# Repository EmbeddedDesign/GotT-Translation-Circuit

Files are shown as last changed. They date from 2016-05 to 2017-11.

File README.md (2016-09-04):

# GotT Translation Circuit 

GotT is a Bluetooth voice modulator circuit for Daleks



## FAQ

### GotT?

["gift of the Time Lord" or "gift of the TARDIS"](http://tardis.wikia.com/wiki/Translation_circuit) depending upon whether you're a Tom Baker or Christopher Eccleston fan respectively.

### What is a "voice modulator"?

A voice modulator is device for altering (or [modulating](https://en.wikipedia.org/wiki/Modulation)) the sound of one's voice.

In the context of Daleks, this usually refers to [ring modulation](https://en.wikipedia.org/wiki/Ring_modulation), whereby two signals mixed (i.e. - multiplied, or [Heterodyned](https://en.wikipedia.org/wiki/Heterodyne)). The first of these signals is typically a voice and the second is often a [sine wave](https://en.wikipedia.org/wiki/Sine_wave) at a frequency of about 30Hz.

This was originally accomplished through the use of a [Moog Ring Modulator similar to this](http://www.moogmusic.com/products/moogerfoogers/mf-102-ring-modulator).

While purists may argue that nothing sounds quite like a pair of audio transformers connected by a ring of four Germanium diodes (which is where the "ring" in "ring modulator" comes from), like the original Moog, GotT accomplishes this task in software.

GotT is a modern modulator for modern Daleks.

## The Board

### Schematic

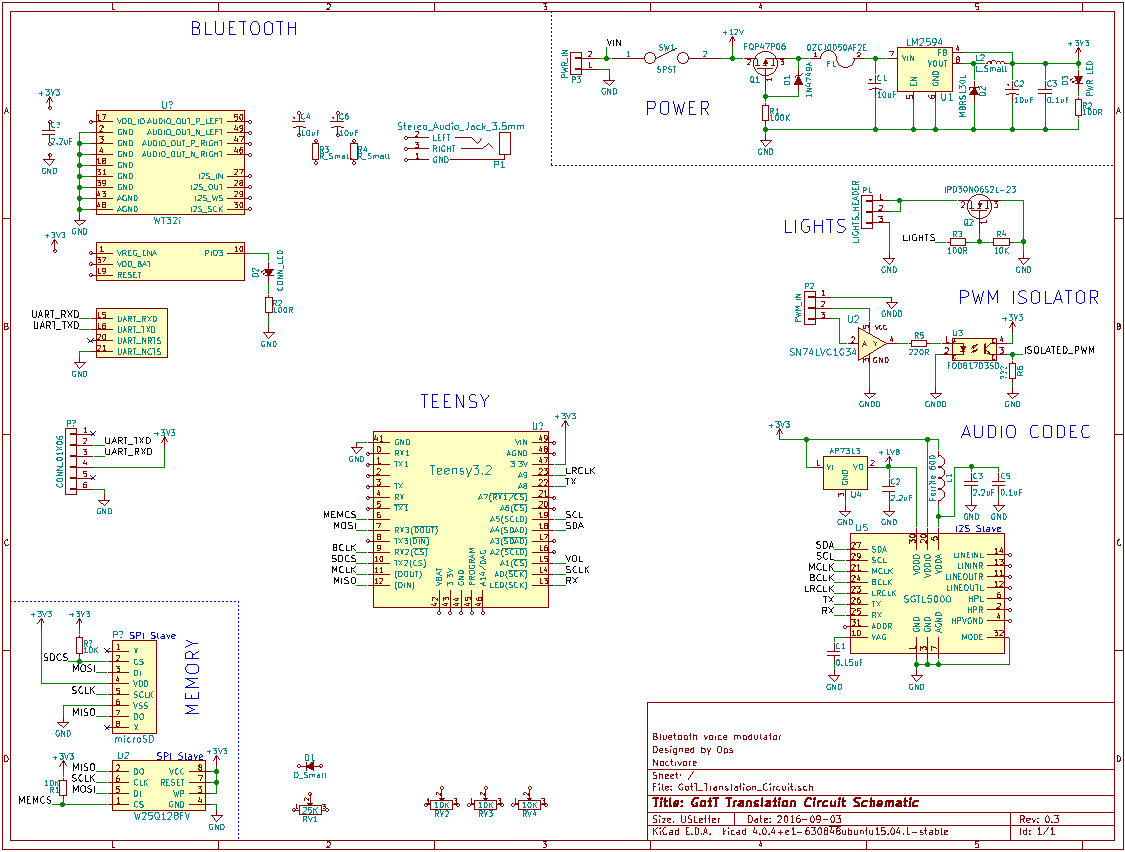
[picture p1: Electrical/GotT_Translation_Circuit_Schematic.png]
GotT Translation Circuit Schematic


All of the design files for the board can be found in the [/Electrical/](https://github.com/EmbeddedDesign/GotT-Translation-Circuit/tree/master/Electrical) subdirectory of this repository.

## Test Boards

Several of the sub-circuits on the GotT including those of the lights, PWM isolator, power, and WT32i were first constructed at test boards to ensure proper concept and functionality prior to integration into the larger design.

A detailed overview of the test boards and deeper descriptions of basic functionality [can be found here](https://noctivore.com/2016/06/12/gott-translation-circuit/).

Images of the schematics and layout along with complete deign files and BOM for each of the test boards can be found in the respective subdirectories of the [/Electrical/Test Boards/](https://github.com/EmbeddedDesign/GotT-Translation-Circuit/tree/master/Electrical/Test%20Boards) section of this repository.

## License

[MIT License](LICENSE) © [Operator](https://github.com/EmbeddedDesign)

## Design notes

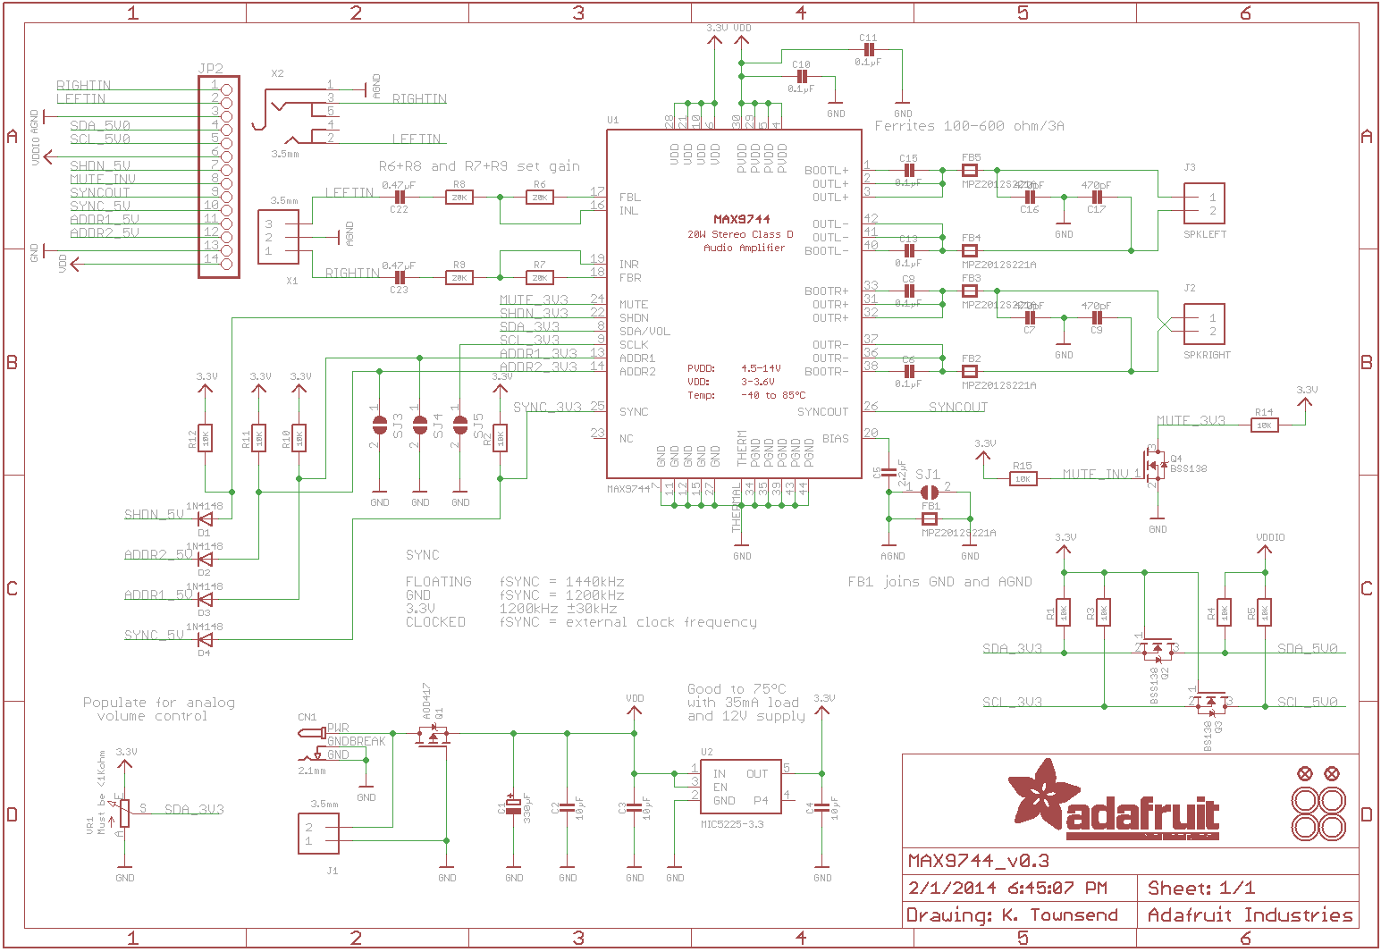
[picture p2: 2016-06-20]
Documentation/Reference Schematics/Adafruit_20W_Stereo_Amp_Schematic.png

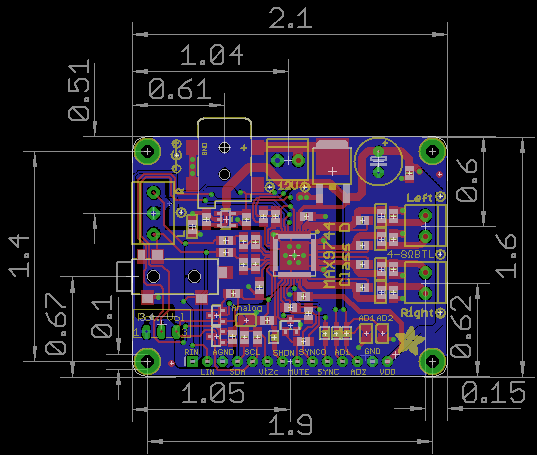
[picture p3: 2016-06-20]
Mechanical/Adafruit_20W_Stereo_Amp_Dimensions_Inch.png

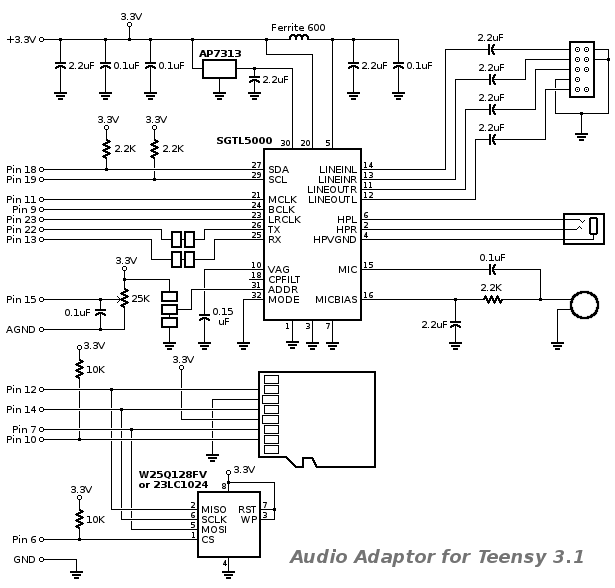
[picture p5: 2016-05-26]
Documentation/Reference Schematics/Teensy3_Audio_Board_Rev2.gif

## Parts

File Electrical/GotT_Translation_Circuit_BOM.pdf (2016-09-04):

GotT Translation Circuit

Page 1

## GotT Translation Circuit BOM

Designator: Quantity: Cost: | Part Number: | Value: | Footprint: | Link: | Alternate Link:
U1 | 1 | $3.28 | LM2594MX-3.3/NOPB | 3.3V, 500mA Switching Regulator
U2 | 1 | $0.36 | SN74LVC1G34DBVR | Buffer, SOT-23-5
U3 | 1 | $0.60 | FOD817D3SD | Optocoupler
U4 | 1 | $0.41 | AP7313-18SAG-7 | 1.8V, 150mA LDO Regulator
U5
U6 | 1 | $1.61 | W25Q128FVSIG | Winbond 128Mb SPI NOR Flash
U7
U8 | 1 | $19.66 WT32i-E-AI6 | WT32i BT Module, U.FL Antenna
Q1 | 1 | $2.25 | FQP47P06 | P-Channel Reverse Protection FET
Q2 | 1 | $0.88 | IPD30N06S2L23ATMA3 | N-Channel MOSFET
D1 | 1 | $0.24 | 1N4749A_T50A | MOSFET Zener Diode
D2 | 1 | $0.44 | 1N5819HW-7-F | Switching Regulator Schottky Diode
D3 | 1 | $0.37 | LG L29K-G2J1-24-Z | PWR LED (Green)
D4 | 1 | $0.35 | LB Q39G-L2OO-35-1 | CONN LED (Blue)
R1 | 1 | $0.10 | CF14JT100K | MOSFET Resistor, 100K Ohm
R2 | 1 | $0.10 | ERJ-3EKF8200V | PWR LED Resistor (820 Ohm), 0603
R3 | 1 | $0.10 | ERJ-3EKF1000V | MOSFET Gate Current Limit Resistor, 1
R4, 7, 8 | 3 | $0.10 | ERJ-3EKF1002V | Pull-up/Pull-down Resistors, 10K Ohm
R5 | 1 | $0.10 | ERJ-3EKF2200V | Input Resistor 220 Ohm, 0603
R6
F1 | 1 | $0.18 | 0ZCJ0050AF2E | PTC Resettable Fuse
C1 | 1 | $0.89 | EEE-FPV680XAP | 68uF Input Bypass Capacitor
C2 | 1 | $1.39 | TPSD107K016R0125 | Output Capacitor, 100uF
C3, 6 | 2 | 0.1uF Filter Capacitors
C4, 5 | 2 | 2.2uF Filter Capacitors
C7 | 1 | 0.15uF Analog Filter Capacitor
L1 | 1 | $3.24 | PE-53820SNL | 115uH Inductor
L2 | 1 | $0.10 | MPZ1608S601ATA00 | Ferrite Bead 600 Ohm at 100MHz
SW1 | 1 | $0.93 | GF-123-0054 | Power Switch
P1
P2 | 1 | $0.53 | 1935174 | Lights Screw Terminal, 01X03
P3 | 1 | $0.27 | 68000-103HLF | 01X03 Male Header
P4
PGT1 | 1 | $4.50 | JF1R6-CR3-4I | U.FL (UMCC) to RP-SMA Female
ANT1 | 1 | $5.00 | 001-0015 | 2.4 GHz u.FL Antenna

Cost/Board:$12.60

http://www.ti.com/lit/ds/symlink/lm2594.pdf https://www.digikey.com/product-detail/en/texas-instruments/LM2594MX-3.3-NOPB/LM2594MX-3.3-NOPBCT-ND/3526877 http://www.mouser.com/ProductDetail/Texas-Instruments/LM2594MX-33-NOPB/?qs=X1J7HmVL2ZEh4uJm8Q5hoQ==
http://www.ti.com/lit/ds/symlink/sn74lvc1g34.pdf https://www.digikey.com/product-detail/en/texas-instruments/SN74LVC1G34DBVR/296-17893-1-ND/738116 http://www.mouser.com/ProductDetail/Texas-Instruments/SN74LVC1G34DBVR/?qs=dT9u2OTAaVXXjYSQb2wcdg==
https://www.fairchildsemi.com/datasheets/FO/FOD817D.pdf https://www.digikey.com/product-detail/en/fairchild-semiconductor/FOD817D3SD/FOD817D3SDCT-ND/3041737 http://www.mouser.com/ProductDetail/Fairchild-Semiconductor/FOD817D3SD/?qs=32VJUWvZ7XaI9Lc6ol43XQ==
http://www.diodes.com/_files/datasheets/AP7313.pdf https://www.digikey.com/product-detail/en/diodes-incorporated/AP7313-18SAG-7/AP7313-18SAG-7DICT-ND/2270838 http://www.mouser.com/ProductDetail/Diodes-Incorporated/AP7313-18SAG-7/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

https://www.winbond.com/resource-files/w25q128fv_revhh1_100913_website1.pdf https://www.digikey.com/product-search/en/integrated-circuits-ics/memory/2556980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

http://www.mouser.com/ds/2/368/Bluegigga%20Technologies_WT32i_Datasheet-558681.pdf https://www.digikey.com/product-detail/en/silicon-labs/WT32I-E-AI6/1446-1037-1-ND/4806564 http://www.mouser.com/ProductDetail/Silicon-Labs-Bluegiga/WT32i-E-AI6/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
https://www.fairchildsemi.com/datasheets/FQ/FQP47P06.pdf https://www.digikey.com/product-detail/en/fairchild-semiconductor/FQP47P06/FQP47P06-ND/1057079 http://www.mouser.com/ProductDetail/Fairchild-Semiconductor/FQP47P06/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
http://www.infineon.com/dgdl/Infineon-IPD30N06S2L_23-DS-v01_00-en.pdf?fileId=db3a304412b407950112b433bafe5d69 https://www.digikey.com/product-detail/en/infineon-technologies/IPD30N06S2L23ATMA3/IPD30N06S2L23ATMA3CT-ND/5440904 http://www.mouser.com/ProductDetail/Infineon-Technologies/IPD30N06S2L23ATMA3/?qs=nKAiUEXvm/A3t2VUC031Ag==
http://www.fairchildsemi.com/datasheets/1N/1N4731A.pdf https://www.digikey.com/product-detail/en/fairchild-semiconductor/1N4749A_T50A/1N4749A_T50AFSCT-ND/3478158 http://www.mouser.com/ProductDetail/Fairchild-Semiconductor/1N4749A_T50A/?qs=9h%2BT/FFCxR/U89fjfSyrjQ==
http://www.diodes.com/_files/datasheets/ds30217.pdf https://www.digikey.com/product-detail/en/diodes-incorporated/1N5819HW-7-F/1N5819HW-FDICT-ND/815283 http://www.mouser.com/ProductDetail/Diodes-Incorporated/1N5819HW-7-F/?qs=NQ47qNm99eDyWTEd07miYA==
http://www.osram-os.com/Graphics/XPic2/00077107_0.pdf https://www.digikey.com/product-detail/en/osram-opto-semiconductors-inc/LG-L29K-G2J1-24-Z/475-2709-1-ND/1938876 http://www.mouser.com/ProductDetail/Osram-Opto-Semiconductor/LG-L29K-G2J1-24-Z/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 (https://media.digikey.com/pdf/Data%20Sheets/Osram%20PDFs/LB_LT%20Q39G.pdf)df/Data Sheets/Osram PDFs/LB_LT Q39G.pdf https://www.digikey.com/product-detail/en/osram-opto-semiconductors-inc/LB-Q39G-L2OO-35-1/475-2816-1-ND/2176355 http://www.mouser.com/ProductDetail/Osram-Opto-Semiconductor/LB-Q39G-L2OO-35-1/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 https://www.digikey.com/product-detail/en/stackpole-electronics-inc/CF14JT100K/CF14JT100KCT-ND/1830399 http://www.mouser.com/ProductDetail/Ohmite/OK1045E-R52/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 https://www.digikey.com/product-detail/en/panasonic-electronic-components/ERJ-3EKF8200V/P820HCT-ND/1746806 http://www.mouser.com/ProductDetail/Panasonic/ERJ-3EKF8200V/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 https://www.digikey.com/product-detail/en/panasonic-electronic-components/ERJ-3EKF1000V/P100HCT-ND/198109 http://www.mouser.com/ProductDetail/Panasonic/ERJ-3EKF1000V/?qs=H7k1u0Mp9JS7i8KGO5m47A==
http://industrial.panasonic.com/www-cgi/jvcr13pz.cgi?E+PZ+3+AOA0002+ERJ3EKF1002V+7+WW https://www.digikey.com/product-detail/en/panasonic-electronic-components/ERJ-3EKF1002V/P10.0KHCT-ND/198102 http://www.mouser.com/ProductDetail/Panasonic/ERJ-3EKF1002V/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 https://www.digikey.com/product-detail/en/panasonic-electronic-components/ERJ-3EKF2200V/P220HCT-ND/1746741 http://www.mouser.com/ProductDetail/Panasonic/ERJ-3EKF2200V/?qs=iBwFsHVUAOcTUCNoJPNpnQ==

http://www.belfuse.com/pdfs/0ZCJ.pdf https://www.digikey.com/product-detail/en/bel-fuse-inc/0ZCJ0050AF2E/507-1803-1-ND/4156312 http://www.mouser.com/ProductDetail/Bel-Fuse/0ZCJ0050AF2E/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 https://www.digikey.com/product-detail/en/panasonic-electronic-components/EEE-FPV680XAP/PCE4553CT-ND/1701052 http://www.mouser.com/ProductDetail/Panasonic/EEE-FPV680XAP/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 https://www.digikey.com/product-detail/en/avx-corporation/TPSD107K016R0125/478-1778-1-ND/564810 http://www.mouser.com/ProductDetail/AVX/TPSD107K016R0125/?qs=Ow%2BOiPmaljGaFh%2BHI/q%2BNg==

http://productfinder.pulseeng.com/products/datasheets/SPM2007_47.pdf https://www.digikey.com/product-detail/en/pulse-electronics-corporation/PE-53820SNL/553-1403-ND/1037014 http://www.mouser.com/ProductDetail/Pulse/PE-53820SNL/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 https://www.digikey.com/product-detail/en/tdk-corporation/MPZ1608S601ATA00/445-2205-1-ND/765103 http://www.mouser.com/ProductDetail/TDK/MPZ1608S601ATA00/?qs=47dIwT2ZIzth0CTKDYh9rw==
https://media.digikey.com/p (https://media.digikey.com/pdf/Data%20Sheets/CW%20Industries%20PDFs/GF-123-0054_Dwg.pdf)df/Data Sheets/CW Industries PDFs/GF-123-0054_Dwg.pdf https://www.digikey.com/product-detail/en/cw-industries/GF-123-0054/CWI333-ND/4089770 http://www.mouser.com/ProductDetail/CW-Industries/GF-123-0054/?qs=n1d6TrdN4SA9FY9ssLiRzw==

https://media.digikey.com/p (https://media.digikey.com/pdf/Data%20Sheets/Phoenix%20Contact%20PDFs/1935174.pdf)df/Data Sheets/Phoenix Contact PDFs/1935174.pdf https://www.digikey.com/product-detail/en/phoenix-contact/1935174/277-1578-ND/568615 http://www.mouser.com/ProductDetail/Phoenix-Contact/1935174/?qs=QWULklcAmSR8B7o4YouITA==
http://portal.fciconnect.com/Comergent//fci/drawing/68000.pdf https://www.digikey.com/product-detail/en/amphenol-fci/68000-103HLF/609-3461-ND/2023309 http://www.mouser.com/ProductDetail/FCI/68000-103HLF/?qs=zh4O8xspOuyqPBhcuxtliw==

http://www.digi.com/products/models/jf1r6-cr3-4i https://www.digikey.com/product-detail/en/digi-international/JF1R6-CR3-4I/JF1R6-CR3-4I-ND/1090366 http://www.mouser.com/ProductDetail/Digi-International/JF1R6-CR3-4I/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 https://www.digikey.com/product-detail/en/lsr/001-0015/001-0015-ND/4732759 http://www.mouser.com/ProductDetail/LS-Research/001-0015/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 DRAFT

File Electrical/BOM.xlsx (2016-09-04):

GotT Translation Circuit BOM
Designator: | Quantity: | Cost: | Part Number: | Value: | Footprint: | Link: | Alternate Link:
U1 | 1 | $3.28 | LM2594MX-3.3/NOPB | 3.3V, 500mA Switching Regulator | http://www.ti.com/lit/ds/symlink/lm2594.pdf | https://www.digikey.com/product-detail/en/texas-instruments/LM2594MX-3.3-NOPB/LM2594MX-3.3-NOPBCT-ND/3526877 | http://www.mouser.com/ProductDetail/Texas-Instruments/LM2594MX-33-NOPB/?qs=X1J7HmVL2ZEh4uJm8Q5hoQ==
U2 | 1 | $0.36 | SN74LVC1G34DBVR | Buffer, SOT-23-5 | http://www.ti.com/lit/ds/symlink/sn74lvc1g34.pdf | https://www.digikey.com/product-detail/en/texas-instruments/SN74LVC1G34DBVR/296-17893-1-ND/738116 | http://www.mouser.com/ProductDetail/Texas-Instruments/SN74LVC1G34DBVR/?qs=dT9u2OTAaVXXjYSQb2wcdg==
U3 | 1 | $0.60 | FOD817D3SD | Optocoupler | https://www.fairchildsemi.com/datasheets/FO/FOD817D.pdf | https://www.digikey.com/product-detail/en/fairchild-semiconductor/FOD817D3SD/FOD817D3SDCT-ND/3041737 | http://www.mouser.com/ProductDetail/Fairchild-Semiconductor/FOD817D3SD/?qs=32VJUWvZ7XaI9Lc6ol43XQ==
U4 | 1 | $0.41 | AP7313-18SAG-7 | 1.8V, 150mA LDO Regulator | http://www.diodes.com/_files/datasheets/AP7313.pdf | https://www.digikey.com/product-detail/en/diodes-incorporated/AP7313-18SAG-7/AP7313-18SAG-7DICT-ND/2270838 | http://www.mouser.com/ProductDetail/Diodes-Incorporated/AP7313-18SAG-7/
U5
U6 | 1 | $1.61 | W25Q128FVSIG | Winbond 128Mb SPI NOR Flash | https://www.winbond.com/resource-files/w25q128fv_revhh1_100913_website1.pdf | https://www.digikey.com/product-search/en/integrated-circuits-ics/memory/2556980?k=w25q128fv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
U7
U8 | 1 | $19.66 | WT32i-E-AI6 | WT32i BT Module, U.FL Antenna | http://www.mouser.com/ds/2/368/Bluegigga%20Technologies_WT32i_Datasheet-558681.pdf | https://www.digikey.com/product-detail/en/silicon-labs/WT32I-E-AI6/1446-1037-1-ND/4806564 | http://www.mouser.com/ProductDetail/Silicon-Labs-Bluegiga/WT32i-E-AI6/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
Q1 | 1 | $2.25 | FQP47P06 | P-Channel Reverse Protection FET | https://www.fairchildsemi.com/datasheets/FQ/FQP47P06.pdf | https://www.digikey.com/product-detail/en/fairchild-semiconductor/FQP47P06/FQP47P06-ND/1057079 | http://www.mouser.com/ProductDetail/Fairchild-Semiconductor/FQP47P06/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
Q2 | 1 | $0.88 | IPD30N06S2L23ATMA3 | N-Channel MOSFET | http://www.infineon.com/dgdl/Infineon-IPD30N06S2L_23-DS-v01_00-en.pdf?fileId=db3a304412b407950112b433bafe5d69 | https://www.digikey.com/product-detail/en/infineon-technologies/IPD30N06S2L23ATMA3/IPD30N06S2L23ATMA3CT-ND/5440904 | http://www.mouser.com/ProductDetail/Infineon-Technologies/IPD30N06S2L23ATMA3/?qs=nKAiUEXvm/A3t2VUC031Ag==
D1 | 1 | $0.24 | 1N4749A_T50A | MOSFET Zener Diode | http://www.fairchildsemi.com/datasheets/1N/1N4731A.pdf | https://www.digikey.com/product-detail/en/fairchild-semiconductor/1N4749A_T50A/1N4749A_T50AFSCT-ND/3478158 | http://www.mouser.com/ProductDetail/Fairchild-Semiconductor/1N4749A_T50A/?qs=9h%2BT/FFCxR/U89fjfSyrjQ==
D2 | 1 | $0.44 | 1N5819HW-7-F | Switching Regulator Schottky Diode | http://www.diodes.com/_files/datasheets/ds30217.pdf | https://www.digikey.com/product-detail/en/diodes-incorporated/1N5819HW-7-F/1N5819HW-FDICT-ND/815283 | http://www.mouser.com/ProductDetail/Diodes-Incorporated/1N5819HW-7-F/?qs=NQ47qNm99eDyWTEd07miYA==
D3 | 1 | $0.37 | LG L29K-G2J1-24-Z | PWR LED (Green) | http://www.osram-os.com/Graphics/XPic2/00077107_0.pdf | https://www.digikey.com/product-detail/en/osram-opto-semiconductors-inc/LG-L29K-G2J1-24-Z/475-2709-1-ND/1938876 | http://www.mouser.com/ProductDetail/Osram-Opto-Semiconductor/LG-L29K-G2J1-24-Z/
D4 | 1 | $0.35 | LB Q39G-L2OO-35-1 | CONN LED (Blue) | https://media.digikey.com/pdf/Data Sheets/Osram PDFs/LB_LT Q39G.pdf (https://media.digikey.com/pdf/Data%20Sheets/Osram%20PDFs/LB_LT%20Q39G.pdf) | https://www.digikey.com/product-detail/en/osram-opto-semiconductors-inc/LB-Q39G-L2OO-35-1/475-2816-1-ND/2176355 | http://www.mouser.com/ProductDetail/Osram-Opto-Semiconductor/LB-Q39G-L2OO-35-1/
R1 | 1 | $0.10 | CF14JT100K | MOSFET Resistor, 100K Ohm | http://www.seielect.com/catalog/SEI-CF_CFM.pdf | https://www.digikey.com/product-detail/en/stackpole-electronics-inc/CF14JT100K/CF14JT100KCT-ND/1830399 | http://www.mouser.com/ProductDetail/Ohmite/OK1045E-R52/?qs=sGAEpiMZZMsPqMdJzcrNwhqiT%2B35FJji0CucJiszflQ=
R2 | 1 | $0.10 | ERJ-3EKF8200V | PWR LED Resistor (820 Ohm), 0603 | http://industrial.panasonic.com/www-cgi/jvcr13pz.cgi?E+PZ+3+AOA0002+ERJ3EKF8200V+7+WW | https://www.digikey.com/product-detail/en/panasonic-electronic-components/ERJ-3EKF8200V/P820HCT-ND/1746806 | http://www.mouser.com/ProductDetail/Panasonic/ERJ-3EKF8200V/
R3 | 1 | $0.10 | ERJ-3EKF1000V | MOSFET Gate Current Limit Resistor, 100 Ohm | http://industrial.panasonic.com/www-cgi/jvcr13pz.cgi?E+PZ+3+AOA0002+ERJ3EKF1000V+7+WW | https://www.digikey.com/product-detail/en/panasonic-electronic-components/ERJ-3EKF1000V/P100HCT-ND/198109 | http://www.mouser.com/ProductDetail/Panasonic/ERJ-3EKF1000V/?qs=H7k1u0Mp9JS7i8KGO5m47A==
R4, 7, 8 | 3 | $0.10 | ERJ-3EKF1002V | Pull-up/Pull-down Resistors, 10K Ohm | http://industrial.panasonic.com/www-cgi/jvcr13pz.cgi?E+PZ+3+AOA0002+ERJ3EKF1002V+7+WW | https://www.digikey.com/product-detail/en/panasonic-electronic-components/ERJ-3EKF1002V/P10.0KHCT-ND/198102 | http://www.mouser.com/ProductDetail/Panasonic/ERJ-3EKF1002V/?qs=H7k1u0Mp9JSrGPQ5/5COuw==
R5 | 1 | $0.10 | ERJ-3EKF2200V | Input Resistor 220 Ohm, 0603 | http://industrial.panasonic.com/www-cgi/jvcr13pz.cgi?E+PZ+3+AOA0002+ERJ3EKF2200V+7+WW | https://www.digikey.com/product-detail/en/panasonic-electronic-components/ERJ-3EKF2200V/P220HCT-ND/1746741 | http://www.mouser.com/ProductDetail/Panasonic/ERJ-3EKF2200V/?qs=iBwFsHVUAOcTUCNoJPNpnQ==
R6
F1 | 1 | $0.18 | 0ZCJ0050AF2E | PTC Resettable Fuse | http://www.belfuse.com/pdfs/0ZCJ.pdf | https://www.digikey.com/product-detail/en/bel-fuse-inc/0ZCJ0050AF2E/507-1803-1-ND/4156312 | http://www.mouser.com/ProductDetail/Bel-Fuse/0ZCJ0050AF2E/?qs=SRYZG9HaIQ3Oqm1PQp276Q==
C1 | 1 | $0.89 | EEE-FPV680XAP | 68uF Input Bypass Capacitor | http://industrial.panasonic.com/cdbs/www-data/pdf/RDE0000/ABA0000C1184.pdf | https://www.digikey.com/product-detail/en/panasonic-electronic-components/EEE-FPV680XAP/PCE4553CT-ND/1701052 | http://www.mouser.com/ProductDetail/Panasonic/EEE-FPV680XAP/?qs=d1CqaRUMZD%2BB3QneHdz%2BNA==
C2 | 1 | $1.39 | TPSD107K016R0125 | Output Capacitor, 100uF | http://datasheets.avx.com/tps.pdf | https://www.digikey.com/product-detail/en/avx-corporation/TPSD107K016R0125/478-1778-1-ND/564810 | http://www.mouser.com/ProductDetail/AVX/TPSD107K016R0125/?qs=Ow%2BOiPmaljGaFh%2BHI/q%2BNg==
C3, 6 | 2 |  |  | 0.1uF Filter Capacitors
C4, 5 | 2 |  |  | 2.2uF Filter Capacitors
C7 | 1 |  |  | 0.15uF Analog Filter Capacitor
L1 | 1 | $3.24 | PE-53820SNL | 115uH Inductor | http://productfinder.pulseeng.com/products/datasheets/SPM2007_47.pdf | https://www.digikey.com/product-detail/en/pulse-electronics-corporation/PE-53820SNL/553-1403-ND/1037014 | http://www.mouser.com/ProductDetail/Pulse/PE-53820SNL/?qs=sGAEpiMZZMsg%2By3WlYCkU6/kcGZFUWykAerZ435ceU4=
L2 | 1 | $0.10 | MPZ1608S601ATA00 | Ferrite Bead 600 Ohm at 100MHz | https://product.tdk.com/info/en/catalog/datasheets/beads_commercial_power_mpz1608_en.pdf | https://www.digikey.com/product-detail/en/tdk-corporation/MPZ1608S601ATA00/445-2205-1-ND/765103 | http://www.mouser.com/ProductDetail/TDK/MPZ1608S601ATA00/?qs=47dIwT2ZIzth0CTKDYh9rw==
SW1 | 1 | $0.93 | GF-123-0054 | Power Switch | https://media.digikey.com/pdf/Data Sheets/CW Industries PDFs/GF-123-0054_Dwg.pdf (https://media.digikey.com/pdf/Data%20Sheets/CW%20Industries%20PDFs/GF-123-0054_Dwg.pdf) | https://www.digikey.com/product-detail/en/cw-industries/GF-123-0054/CWI333-ND/4089770 | http://www.mouser.com/ProductDetail/CW-Industries/GF-123-0054/?qs=n1d6TrdN4SA9FY9ssLiRzw==
P1
P2 | 1 | $0.53 | 1935174 | Lights Screw Terminal, 01X03 | https://media.digikey.com/pdf/Data Sheets/Phoenix Contact PDFs/1935174.pdf (https://media.digikey.com/pdf/Data%20Sheets/Phoenix%20Contact%20PDFs/1935174.pdf) | https://www.digikey.com/product-detail/en/phoenix-contact/1935174/277-1578-ND/568615 | http://www.mouser.com/ProductDetail/Phoenix-Contact/1935174/?qs=QWULklcAmSR8B7o4YouITA==
P3 | 1 | $0.27 | 68000-103HLF | 01X03 Male Header | http://portal.fciconnect.com/Comergent//fci/drawing/68000.pdf | https://www.digikey.com/product-detail/en/amphenol-fci/68000-103HLF/609-3461-ND/2023309 | http://www.mouser.com/ProductDetail/FCI/68000-103HLF/?qs=zh4O8xspOuyqPBhcuxtliw==
P4
PGT1 | 1 | $4.50 | JF1R6-CR3-4I | U.FL (UMCC) to RP-SMA Female | http://www.digi.com/products/models/jf1r6-cr3-4i | https://www.digikey.com/product-detail/en/digi-international/JF1R6-CR3-4I/JF1R6-CR3-4I-ND/1090366 | http://www.mouser.com/ProductDetail/Digi-International/JF1R6-CR3-4I/
ANT1 | 1 | $5.00 | 001-0015 | 2.4 GHz u.FL Antenna | http://www.lsr.com/downloads/products/330-0150.pdf | https://www.digikey.com/product-detail/en/lsr/001-0015/001-0015-ND/4732759 | http://www.mouser.com/ProductDetail/LS-Research/001-0015/
 | Cost/Board: | $12.60

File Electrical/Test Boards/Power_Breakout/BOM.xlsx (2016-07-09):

Designator: | Quantity: | Cost: | Part Number: | Value: | Footprint: | Link: | Link (Alternate):
U1 | 1 | $3.28 | LM2594MX-3.3/NOPB | 3.3V, 500mA Switching Regulator | http://www.ti.com/lit/ds/symlink/lm2594.pdf | https://www.digikey.com/product-detail/en/texas-instruments/LM2594MX-3.3-NOPB/LM2594MX-3.3-NOPBCT-ND/3526877 | http://www.mouser.com/ProductDetail/Texas-Instruments/LM2594MX-33-NOPB/?qs=X1J7HmVL2ZEh4uJm8Q5hoQ==
Q1 | 1 | $2.25 | FQP47P06 | P-Channel Reverse Protection FET | https://www.fairchildsemi.com/datasheets/FQ/FQP47P06.pdf | https://www.digikey.com/product-detail/en/fairchild-semiconductor/FQP47P06/FQP47P06-ND/1057079 | http://www.mouser.com/ProductDetail/Fairchild-Semiconductor/FQP47P06/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
D1 | 1 | $0.24 | 1N4749A_T50A | MOSFET Zener Diode | http://www.fairchildsemi.com/datasheets/1N/1N4731A.pdf | https://www.digikey.com/product-detail/en/fairchild-semiconductor/1N4749A_T50A/1N4749A_T50AFSCT-ND/3478158 | http://www.mouser.com/ProductDetail/Fairchild-Semiconductor/1N4749A_T50A/?qs=9h%2BT/FFCxR/U89fjfSyrjQ==
D2 | 1 | $0.44 | 1N5819HW-7-F | Switching Regulator Schottky Diode | http://www.diodes.com/_files/datasheets/ds30217.pdf | https://www.digikey.com/product-detail/en/diodes-incorporated/1N5819HW-7-F/1N5819HW-FDICT-ND/815283 | http://www.mouser.com/ProductDetail/Diodes-Incorporated/1N5819HW-7-F/?qs=NQ47qNm99eDyWTEd07miYA==
D3 | 1 | $0.35 | LB Q39G-L2OO-35-1 | PWR LED (Blue) | https://media.digikey.com/pdf/Data Sheets/Osram PDFs/LB_LT Q39G.pdf (https://media.digikey.com/pdf/Data%20Sheets/Osram%20PDFs/LB_LT%20Q39G.pdf) | https://www.digikey.com/product-detail/en/osram-opto-semiconductors-inc/LB-Q39G-L2OO-35-1/475-2816-1-ND/2176355 | http://www.mouser.com/ProductDetail/Osram-Opto-Semiconductor/LB-Q39G-L2OO-35-1/
R1 | 1 | $0.10 | CF14JT100K | MOSFET Resistor, 100K Ohm | http://www.seielect.com/catalog/SEI-CF_CFM.pdf | https://www.digikey.com/product-detail/en/stackpole-electronics-inc/CF14JT100K/CF14JT100KCT-ND/1830399 | http://www.mouser.com/ProductDetail/Ohmite/OK1045E-R52/?qs=sGAEpiMZZMsPqMdJzcrNwhqiT%2B35FJji0CucJiszflQ=
R2 | 1 | $0.10 | ERJ-3EKF1000V | PWR LED Resistor, 100 Ohm, 0603 | http://industrial.panasonic.com/www-cgi/jvcr13pz.cgi?E+PZ+3+AOA0002+ERJ3EKF1000V+7+WW | https://www.digikey.com/product-detail/en/panasonic-electronic-components/ERJ-3EKF1000V/P100HCT-ND/198109 | http://www.mouser.com/ProductDetail/Panasonic/ERJ-3EKF1000V/
F1 | 1 | $0.18 | 0ZCJ0050AF2E | PTC Resettable Fuse | http://www.belfuse.com/pdfs/0ZCJ.pdf | https://www.digikey.com/product-detail/en/bel-fuse-inc/0ZCJ0050AF2E/507-1803-1-ND/4156312 | http://www.mouser.com/ProductDetail/Bel-Fuse/0ZCJ0050AF2E/?qs=SRYZG9HaIQ3Oqm1PQp276Q==
C1 | 1 | $0.89 | EEE-FPV680XAP | 68uF Input Bypass Capacitor | http://industrial.panasonic.com/cdbs/www-data/pdf/RDE0000/ABA0000C1184.pdf | https://www.digikey.com/product-detail/en/panasonic-electronic-components/EEE-FPV680XAP/PCE4553CT-ND/1701052 | http://www.mouser.com/ProductDetail/Panasonic/EEE-FPV680XAP/?qs=d1CqaRUMZD%2BB3QneHdz%2BNA==
C2 | 1 | $1.39 | TPSD107K016R0125 | Output Capacitor, 100uF | http://datasheets.avx.com/tps.pdf | https://www.digikey.com/product-detail/en/avx-corporation/TPSD107K016R0125/478-1778-1-ND/564810 | http://www.mouser.com/ProductDetail/AVX/TPSD107K016R0125/?qs=Ow%2BOiPmaljGaFh%2BHI/q%2BNg==
L1 | 1 | $3.24 | PE-53820SNL | 115uH Inductor | http://productfinder.pulseeng.com/products/datasheets/SPM2007_47.pdf | https://www.digikey.com/product-detail/en/pulse-electronics-corporation/PE-53820SNL/553-1403-ND/1037014 | http://www.mouser.com/ProductDetail/Pulse/PE-53820SNL/?qs=sGAEpiMZZMsg%2By3WlYCkU6/kcGZFUWykAerZ435ceU4=
S1 | 1 | $0.93 | GF-123-0054 | Power Switch | https://media.digikey.com/pdf/Data Sheets/CW Industries PDFs/GF-123-0054_Dwg.pdf (https://media.digikey.com/pdf/Data%20Sheets/CW%20Industries%20PDFs/GF-123-0054_Dwg.pdf) | https://www.digikey.com/product-detail/en/cw-industries/GF-123-0054/CWI333-ND/4089770 | http://www.mouser.com/ProductDetail/CW-Industries/GF-123-0054/?qs=n1d6TrdN4SA9FY9ssLiRzw==
CON1 | 1 | $1.96 | PJ-036AH-SMT-TR | DC Barrel Jack | http://www.cui.com/product/resource/digikeypdf/pj-036ah-smt.pdf | https://www.digikey.com/product-detail/en/cui-inc/PJ-036AH-SMT-TR/CP-036AHPJCT-ND/1530994 | http://www.mouser.com/ProductDetail/CUI/PJ-036AH-SMT-TR/?qs=WyjlAZoYn52SyDl2EH3QRQ==
TP1,2,3,4 | 4 | $0.16 | RCS-0C | Test Point | http://www.te.com/commerce/DocumentDelivery/DDEController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 | https://www.digikey.com/product-detail/en/te-connectivity-amp-connectors/RCS-0C/A106143CT-ND/3477800 | http://www.mouser.com/ProductDetail/TE-Connectivity-Holsworthy/RCS-0C/?qs=ip69W3eHERVjlVbETUUe0w==
 | 1 | $0.56 | SQP500JB-6R8 | 485mA Dummy Load, 5W | http://www.yageo.com/documents/recent/Yageo LR_SQP NSP_2013.pdf | https://www.digikey.com/product-detail/en/yageo/SQP500JB-6R8/6.8W-5-ND/18651 | http://www.mouser.com/ProductDetail/ARCOL-Ohmite/ACS-5s-6R8-J-TR/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
 | Cost/Board: | $16.55

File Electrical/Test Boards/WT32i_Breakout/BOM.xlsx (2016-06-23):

Designator: | Quantity: | Cost: | Part Number: | Value: | Footprint: | Link: | Link (Alternate): | Alternate Part: | Link: | Link (Alternate):
U1 | 1 | $19.66 | WT32i-E-AI6 | WT32i u.FL Antenna | https://media.digikey.com/pdf/Data Sheets/BlueGiga PDFs/WT32i_DS_V1.21.pdf (https://media.digikey.com/pdf/Data%20Sheets/BlueGiga%20PDFs/WT32i_DS_V1.21.pdf) | https://www.digikey.com/product-detail/en/silicon-labs/WT32I-E-AI6/1446-1037-1-ND/4806564 | http://www.mouser.com/ProductDetail/Bluegiga-Technologies/WT32i-E-AI6/
U2 | 1 | $0.92 | TPS79933DDCR | 3.3V LDO Regulator | http://www.ti.com/lit/ds/symlink/tps799.pdf | https://www.digikey.com/product-search/en/integrated-circuits-ics/pmic-voltage-regulators-linear/2556290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 | http://www.mouser.com/ProductDetail/Texas-Instruments/TPS79933DDCR/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
P4 | 1 | $1.34 | SJ-3523-SMT-TR | 3.5mm Stereo Jack | http://www.cui.com/product/resource/digikeypdf/sj-352x-smt_series.pdf | https://www.digikey.com/product-search/en/connectors-interconnects/barrel-audio-connectors/1443095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 | http://www.mouser.com/ProductDetail/CUI-Inc/SJ-3523-SMT-TR/
D2 | 1 | $0.35 | LB Q39G-L2OO-35-1 | CONN LED (Blue) | https://media.digikey.com/pdf/Data Sheets/Osram PDFs/LB_LT Q39G.pdf (https://media.digikey.com/pdf/Data%20Sheets/Osram%20PDFs/LB_LT%20Q39G.pdf) | https://www.digikey.com/product-detail/en/osram-opto-semiconductors-inc/LB-Q39G-L2OO-35-1/475-2816-1-ND/2176355 | http://www.mouser.com/ProductDetail/Osram-Opto-Semiconductor/LB-Q39G-L2OO-35-1/
D3 | 1 | $0.37 | LG L29K-G2J1-24-Z | PWR LED (Green) | http://www.osram-os.com/Graphics/XPic2/00077107_0.pdf | https://www.digikey.com/product-detail/en/osram-opto-semiconductors-inc/LG-L29K-G2J1-24-Z/475-2709-1-ND/1938876 | http://www.mouser.com/ProductDetail/Osram-Opto-Semiconductor/LG-L29K-G2J1-24-Z/
C1,2 | 2 | $0.12 | GRM188R61C225KE15D | 2.2uF Ceramic Cpacitor, 0603 | http://search.murata.co.jp/Ceramy/image/img/A01X/G101/ENG/GRM188R61C225KE15-01.pdf | https://www.digikey.com/product-detail/en/murata-electronics-north-america/GRM188R61C225KE15D/490-3296-1-ND/702837 | http://www.mouser.com/ProductDetail/Murata-Electronics/GRM188R61C225KE15D/?qs=hib6TRO3foO3n4uH6cyJAg==
C3,4 | 2 | $2.17 | 6TPF330M9L | 330uF/6.3V/20%/TAN/ESR<10mOhm | http://www.kemet.com/docfinder?Partnumber=T520 | https://www.digikey.com/product-detail/en/kemet/T520D337M006ATE009/399-10418-1-ND/3880189 | http://www.mouser.com/ProductDetail/Kemet/T520D337M006ATE009/?qs=F4vAmCFCeavzfa2EBT2i1w== | 6TPF330M9L | https://www.digikey.com/product-detail/en/panasonic-electronic-components/6TPF330M9L/P16258CT-ND/4146701 | http://www.mouser.com/ProductDetail/Panasonic/6TPF330M9L/
C5,6 | 2 | $0.16 | GRM1885C1H330FA01D | 33pF/50V/C0G/+/-0.5pF, 0603 | http://www.murata.com/~/media/webrenewal/support/library/catalog/products/capacitor/mlcc/c02e.pdf | https://www.digikey.com/product-detail/en/murata-electronics-north-america/GRM1885C1H330FA01D/490-9720-1-ND/4934879 | http://www.mouser.com/ProductDetail/Murata-Electronics/GRM1885C1H330FA01D/?qs=ECEo0ueu72kvzV2E3JDz6g==
L1,2 | 2 | $0.10 | MLK1005S33NJT000 | 33nH+/-5%, 200mA, 0.9ohm, 0402 | https://product.tdk.com/info/en/catalog/datasheets/inductor_commercial_high-frequency_mlk1005_en.pdf | https://www.digikey.com/product-detail/en/tdk-corporation/MLK1005S33NJT000/445-1473-1-ND/571781 | http://www.mouser.com/ProductDetail/TDK/MLK1005S33NJT000/?qs=/PzWLGNeQ%2Bg00frD1iDUEg==
R1 | 1 | $0.10 | ERJ-3EKF1000V | CONN LED Resistor (100 Ohm), 0603 | http://industrial.panasonic.com/www-cgi/jvcr13pz.cgi?E+PZ+3+AOA0002+ERJ3EKF1000V+7+WW | https://www.digikey.com/product-detail/en/panasonic-electronic-components/ERJ-3EKF1000V/P100HCT-ND/198109 | http://www.mouser.com/ProductDetail/Panasonic/ERJ-3EKF1000V/
R2 | 1 | $0.10 | ERJ-3EKF8200V | PWR LED Resistor (820 Ohm), 0603 | http://industrial.panasonic.com/www-cgi/jvcr13pz.cgi?E+PZ+3+AOA0002+ERJ3EKF8200V+7+WW | https://www.digikey.com/product-detail/en/panasonic-electronic-components/ERJ-3EKF8200V/P820HCT-ND/1746806 | http://www.mouser.com/ProductDetail/Panasonic/ERJ-3EKF8200V/
R3,4 | 2 | $0.10 | ERJ-3GEYJ105V | 1M/50V/0.1W/5%, 0603 | http://industrial.panasonic.com/www-cgi/jvcr13pz.cgi?E+PZ+3+AOA0001+ERJ3GEYJ105V+7+WW | https://www.digikey.com/product-search/en/resistors/chip-resistor-surface-mount/65769?k=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 | http://www.mouser.com/ProductDetail/Panasonic/ERJ-3GEYJ105V/?qs=66DK8nO8gJAFuT6JGu2rQw==
P1 | 1 | $0.32 | 68000-206HLF | 01X06 Male Through Hole Header | http://portal.fciconnect.com/Comergent//fci/drawing/68000.pdf | https://www.digikey.com/product-detail/en/amphenol-fci/68000-206HLF/609-3256-ND/1878496 | http://www.mouser.com/ProductDetail/FCI-Amphenol/68000-206HLF/
P2 | 1 | $0.32 | 68000-104HLF | 01X04 Male Through Hole Header | http://portal.fciconnect.com/Comergent//fci/drawing/68000.pdf | https://www.digikey.com/product-detail/en/amphenol-fci/68000-104HLF/609-3248-ND/1878462 | http://www.mouser.com/ProductDetail/Amphenol-FCI/68000-104HLF/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
P3 | 1 | $0.27 | 68000-103HLF | 01X03 Male Through Hole Header | http://portal.fciconnect.com/Comergent//fci/drawing/68000.pdf | https://www.digikey.com/product-detail/en/amphenol-fci/68000-103HLF/609-3461-ND/2023309 | http://www.mouser.com/ProductDetail/Amphenol-FCI/68000-103HLF/?qs=zh4O8xspOuyqPBhcuxtliw==
ANT1 | 1 | $5.00 | 001-0015 | 2.4 GHz u.FL Antenna | http://www.lsr.com/downloads/products/330-0150.pdf | https://www.digikey.com/product-detail/en/lsr/001-0015/001-0015-ND/4732759 | http://www.mouser.com/ProductDetail/LS-Research/001-0015/
 | Cost/Board: | #VALUE!

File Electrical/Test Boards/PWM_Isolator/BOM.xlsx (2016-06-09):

Designator: | Quantity: | Cost: | Part Number: | Value: | Footprint: | Link: | Link (Alternate):
U1 | 1 | $0.36 | SN74LVC1G34DBVR | Buffer, SOT-23-5 | http://www.ti.com/lit/ds/symlink/sn74lvc1g34.pdf | https://www.digikey.com/product-detail/en/texas-instruments/SN74LVC1G34DBVR/296-17893-1-ND/738116 | http://www.mouser.com/ProductDetail/Texas-Instruments/SN74LVC1G34DBVR/?qs=dT9u2OTAaVXXjYSQb2wcdg==
U2 | 1 | $0.60 | FOD817D3SD | Optocoupler | https://www.fairchildsemi.com/datasheets/FO/FOD817D.pdf | https://www.digikey.com/product-detail/en/fairchild-semiconductor/FOD817D3SD/FOD817D3SDCT-ND/3041737 | http://www.mouser.com/ProductDetail/Fairchild-Semiconductor/FOD817D3SD/?qs=32VJUWvZ7XaI9Lc6ol43XQ==
R1 | 1 | $0.10 | ERJ-3EKF2200V | Input Resistor 220 Ohm, 0603 | http://industrial.panasonic.com/www-cgi/jvcr13pz.cgi?E+PZ+3+AOA0002+ERJ3EKF2200V+7+WW | https://www.digikey.com/product-detail/en/panasonic-electronic-components/ERJ-3EKF2200V/P220HCT-ND/1746741 | http://www.mouser.com/ProductDetail/Panasonic/ERJ-3EKF2200V/?qs=iBwFsHVUAOcTUCNoJPNpnQ==
RV1 | 1 | $0.43 | 3306F-1-103 | Output Trimmer Potentiometer | http://www.bourns.com/docs/Product-Datasheets/3306.pdf | https://www.digikey.com/product-detail/en/bourns-inc/3306F-1-103/3306F-103-ND/84666 | http://www.mouser.com/ProductDetail/Bourns/3306F-1-103/?qs=lKPmECyLdCwn927ZmtxV0Q==
P1 | 1 | $0.27 | 68000-103HLF | 01X03 Male Header | http://portal.fciconnect.com/Comergent//fci/drawing/68000.pdf | https://www.digikey.com/product-detail/en/amphenol-fci/68000-103HLF/609-3461-ND/2023309 | http://www.mouser.com/ProductDetail/FCI/68000-103HLF/?qs=zh4O8xspOuyqPBhcuxtliw==
 | Cost/Board: | $1.76

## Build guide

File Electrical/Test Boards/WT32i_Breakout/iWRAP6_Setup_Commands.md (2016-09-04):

    +-----------------------------------------------------------------------+
    | A -    Serial Device      : /dev/ttyUSB0                              |
    | B - Lockfile Location     : /var/lock                                 |
    | C -   Callin Program      :                                           |
    | D -  Callout Program      :                                           |
    | E -    Bps/Par/Bits       : 115200 8N1                                |
    | F - Hardware Flow Control : No                                        |
    | G - Software Flow Control : No                                        |
    |                                                                       |
    |    Change which setting?                                              |
    +-----------------------------------------------------------------------+
            | Screen and keyboard      |
            | Save setup as dfl        |
            | Save setup as..          |
            | Exit                     |
            | Exit from Minicom        |
            +--------------------------+

�p����WRAP THOR AI (6.0.0 build 952)                                         
Copyright (c) 2003-2014 Bluegiga Technologies Inc.                           
READY.                                                                       
                                                                             
at                                                                           
OK

set                                     
SET BT BDADDR 00:07:80:ce:0b:39         
SET BT NAME WT32i-E                     
SET BT CLASS 001f00                     
SET BT IDENT BT:47 f000 6.0.0 Bluegiga iWRAP
SET BT LAP 9e8b33
SET BT PAGEMODE 4 2000 1
SET BT POWER 6 6 6
SET BT ROLE 0 f 2580
SET BT SNIFF 0 20 1 8
SET BT SSP 3 0
SET BT MTU 667
SET CONTROL AUDIO INTERNAL INTERNAL
SET CONTROL BAUD 115200,8n1
SET CONTROL CD 00 0
SET CONTROL CODEC SBC JOINT_STEREO 44100 0
SET CONTROL CONFIG 0000 0000 0000 1100
SET CONTROL ECHO 7
SET CONTROL ESCAPE 43 00 1
SET CONTROL GAIN 8 8
SET CONTROL MICBIAS b 0
SET CONTROL MSC DTE 00 00 00 00 00 00
SET CONTROL PIO 00 00 00
SET CONTROL PREAMP 1 1
SET CONTROL READY 00
SET CONTROL VREGEN 0 00
SET PROFILE SPP Bluetooth Serial Port
SET

Turn headset on and put in pair mode

inquiry 5
INQUIRY_PARTIAL 0c:e0:e4:6a:01:8e 240404
INQUIRY 1
INQUIRY 0c:e0:e4:6a:01:8e 240404

set profile hsp-ag on
set bt class 200204
reset
WRAP THOR AI (6.0.0 build 952)
Copyright (c) 2003-2014 Bluegiga Technologies Inc.
READY.
set
SET BT BDADDR 00:07:80:ce:0b:39
SET BT NAME WT32i-E
SET BT CLASS 200204
SET BT IDENT BT:47 f000 6.0.0 Bluegiga iWRAP
SET BT LAP 9e8b33
SET BT PAGEMODE 4 2000 1
SET BT POWER 6 6 6
SET BT ROLE 0 f 2580
SET BT SNIFF 0 20 1 8
SET BT SSP 3 0
SET BT MTU 667
SET CONTROL AUDIO INTERNAL INTERNAL
SET CONTROL BAUD 115200,8n1
SET CONTROL CD 00 0
SET CONTROL CODEC SBC JOINT_STEREO 44100 0
SET CONTROL CONFIG 0000 0000 0000 1100
SET CONTROL ECHO 7
SET CONTROL ESCAPE 43 00 1
SET CONTROL GAIN 8 8
SET CONTROL MICBIAS b 0
SET CONTROL MSC DTE 00 00 00 00 00 00
SET CONTROL PIO 00 00 00
SET CONTROL PREAMP 1 1
SET CONTROL READY 00
SET CONTROL VREGEN 0 00
SET PROFILE SPP Bluetooth Serial Port
SET PROFILE HSP-AG Voice Gateway
SET

set bt ssp 3 0
set bt auth * 0000
reset
WRAP THOR AI (6.0.0 build 952)
Copyright (c) 2003-2014 Bluegiga Technologies Inc.
READY.

set control cd 8 0

pair 0c:e0:e4:6a:01:8e
PAIR 0c:e0:e4:6a:01:8e OK

RING 0 0c:e0:e4:6a:01:8e 5 HSP-AG 
HSP-AG 0 VOLUME 8
HSP-AG 0 MIC 15

press call button

HSP-AG 0 BUTTON
CONNECT 1 SCO

volume 10
VOLUME 10

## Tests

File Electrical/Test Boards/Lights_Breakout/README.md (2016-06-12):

# Lights Test Board Breakout

## Schematic

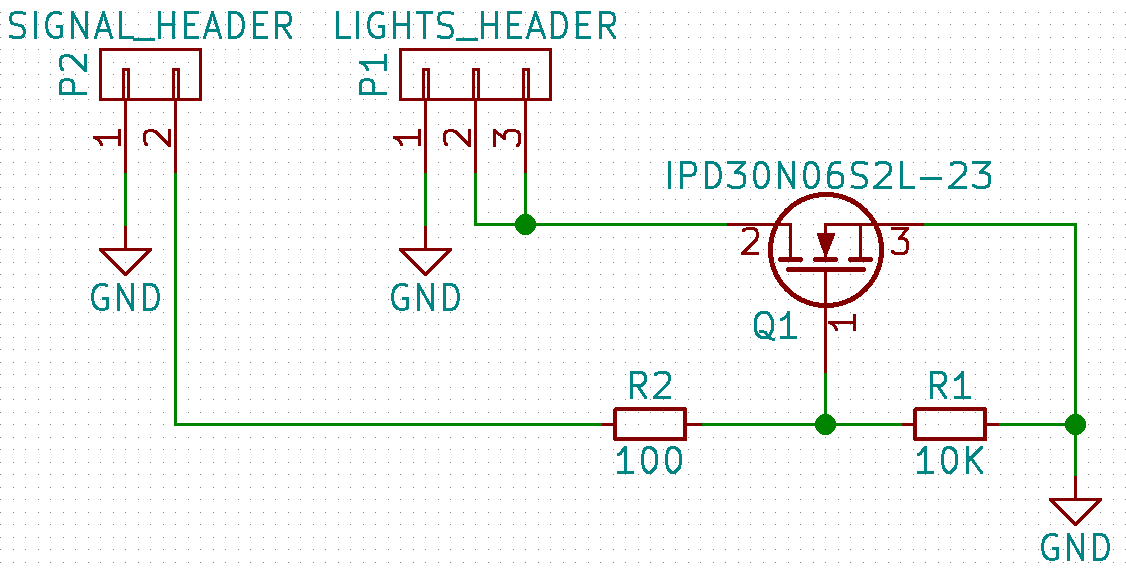
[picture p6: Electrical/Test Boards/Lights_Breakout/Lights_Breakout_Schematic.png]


## Layout

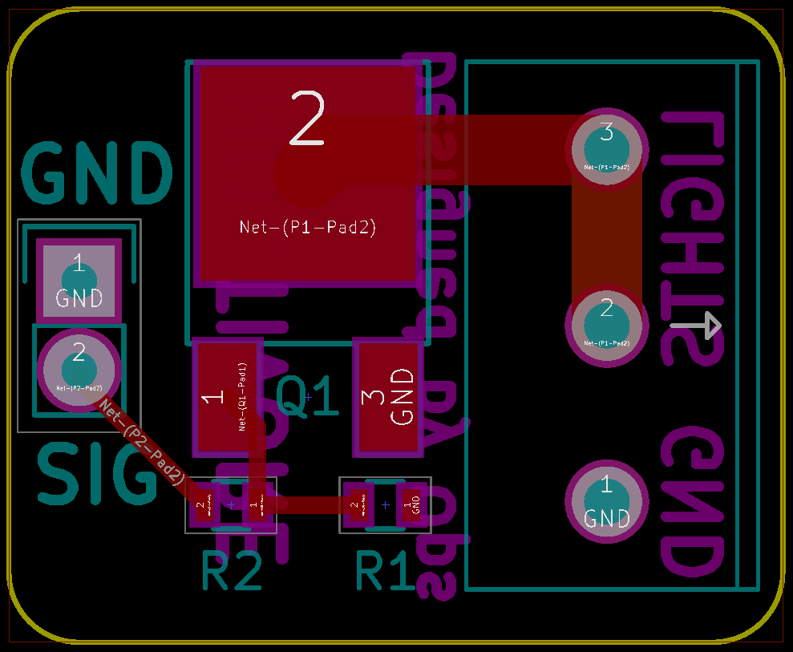
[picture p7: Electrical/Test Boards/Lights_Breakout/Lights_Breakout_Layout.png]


## License

[MIT License](LICENSE) © [Operator](https://github.com/EmbeddedDesign)

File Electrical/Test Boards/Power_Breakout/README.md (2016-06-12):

# Power Test Board Breakout

## Schematic

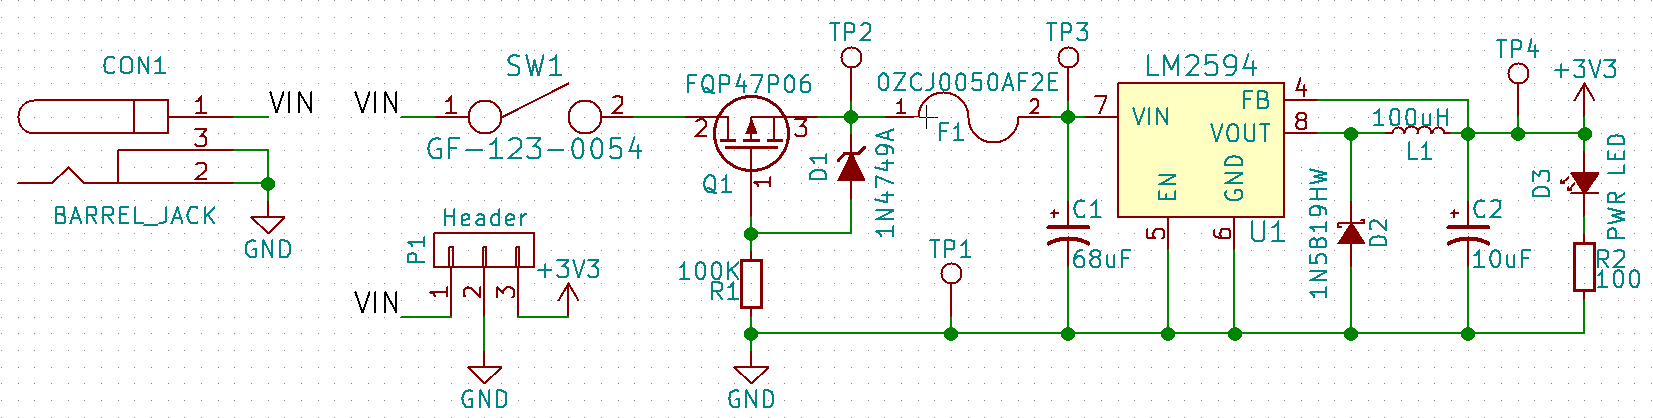
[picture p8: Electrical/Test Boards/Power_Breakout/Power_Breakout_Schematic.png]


## Layout

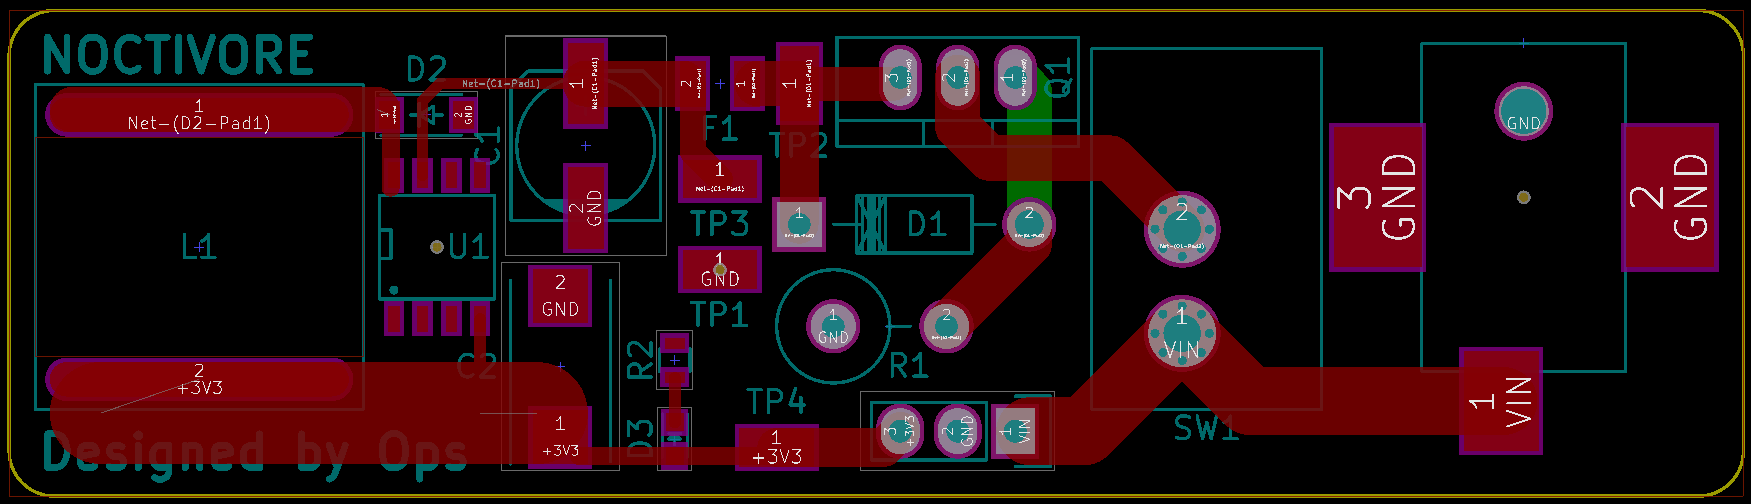
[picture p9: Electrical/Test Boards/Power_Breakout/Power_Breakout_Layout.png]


## License

[MIT License](LICENSE) © [Operator](https://github.com/EmbeddedDesign)

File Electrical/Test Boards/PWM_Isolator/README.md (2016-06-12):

# PWM Isolator Test Board Breakout

## Schematic

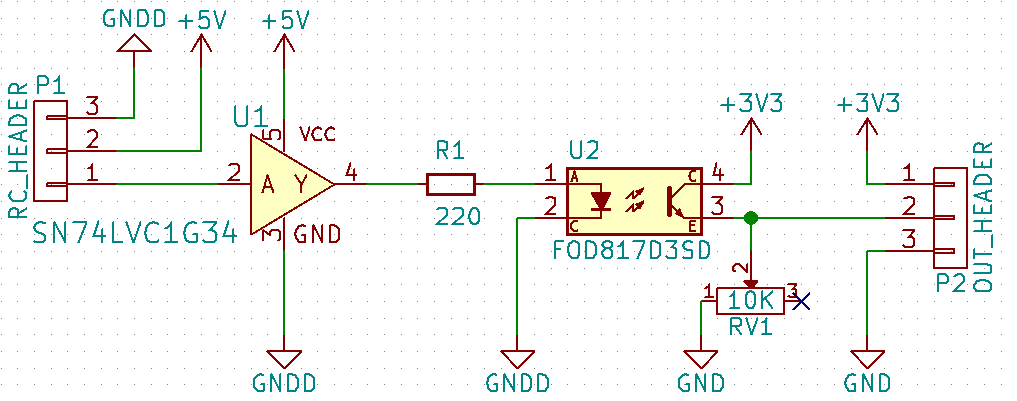
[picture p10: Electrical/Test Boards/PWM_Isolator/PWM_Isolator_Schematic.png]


## Layout

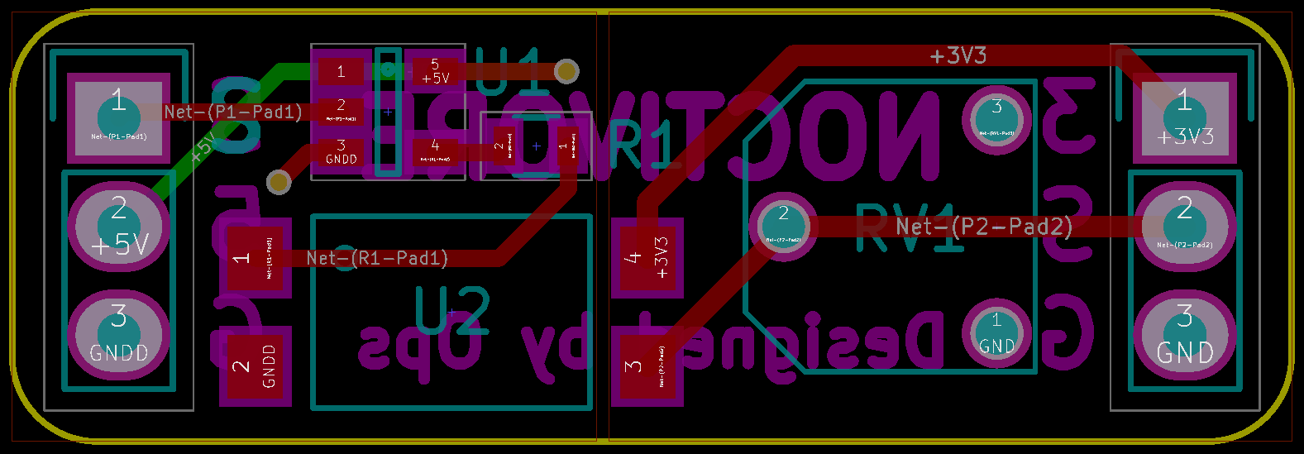
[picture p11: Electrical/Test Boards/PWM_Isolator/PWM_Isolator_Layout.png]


## License

[MIT License](LICENSE) © [Operator](https://github.com/EmbeddedDesign)

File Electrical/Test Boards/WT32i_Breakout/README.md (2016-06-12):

# WT32i Test Board Breakout

## Schematic

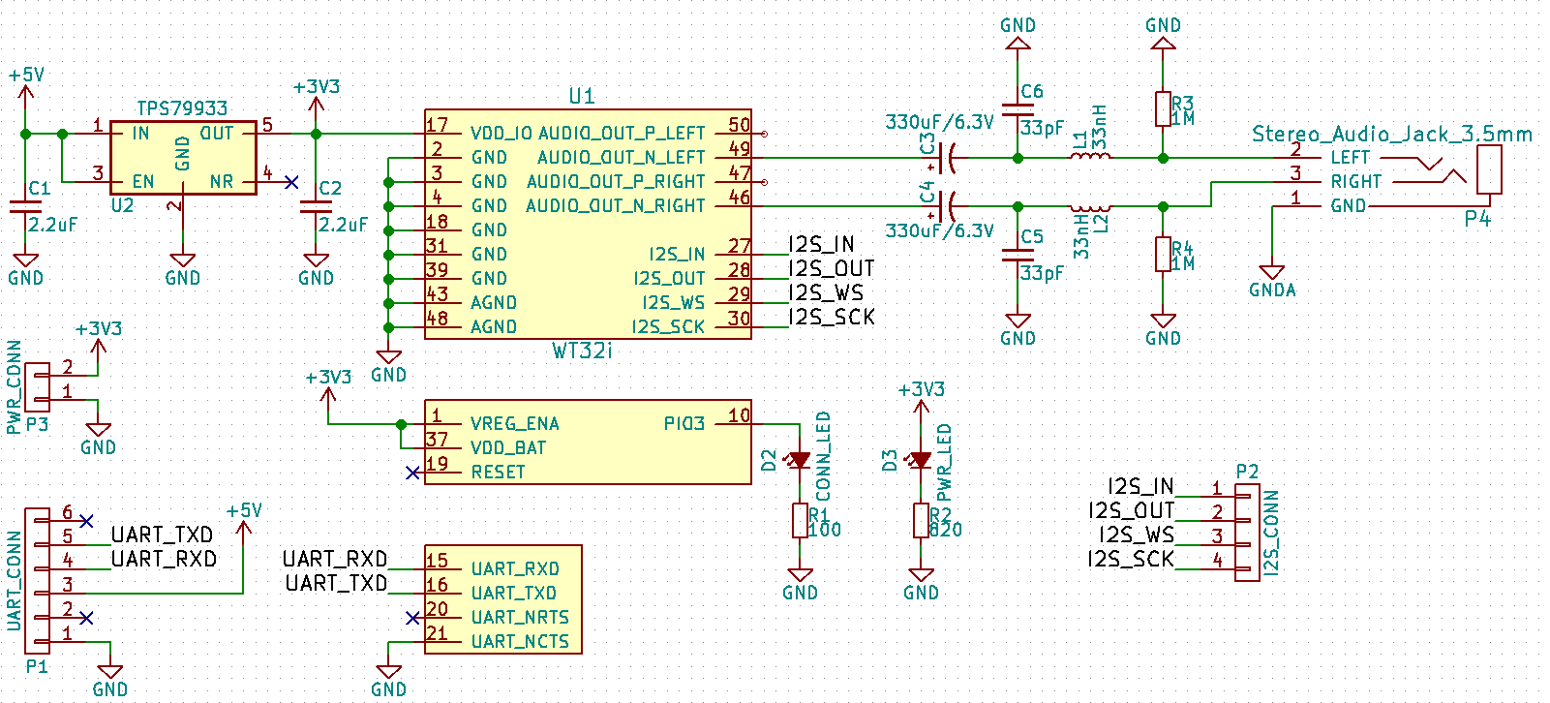
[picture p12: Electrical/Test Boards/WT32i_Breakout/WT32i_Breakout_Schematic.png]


## Layout

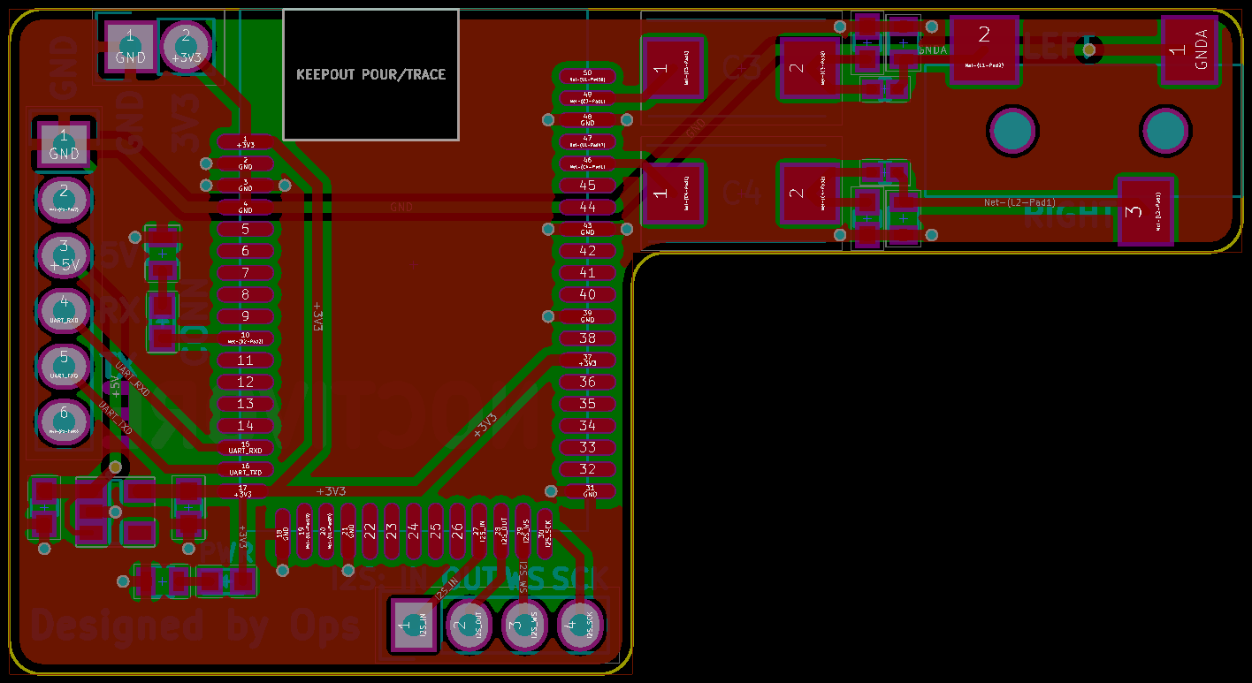
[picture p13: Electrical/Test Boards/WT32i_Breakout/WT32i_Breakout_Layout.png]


## License

[MIT License](LICENSE) © [Operator](https://github.com/EmbeddedDesign)

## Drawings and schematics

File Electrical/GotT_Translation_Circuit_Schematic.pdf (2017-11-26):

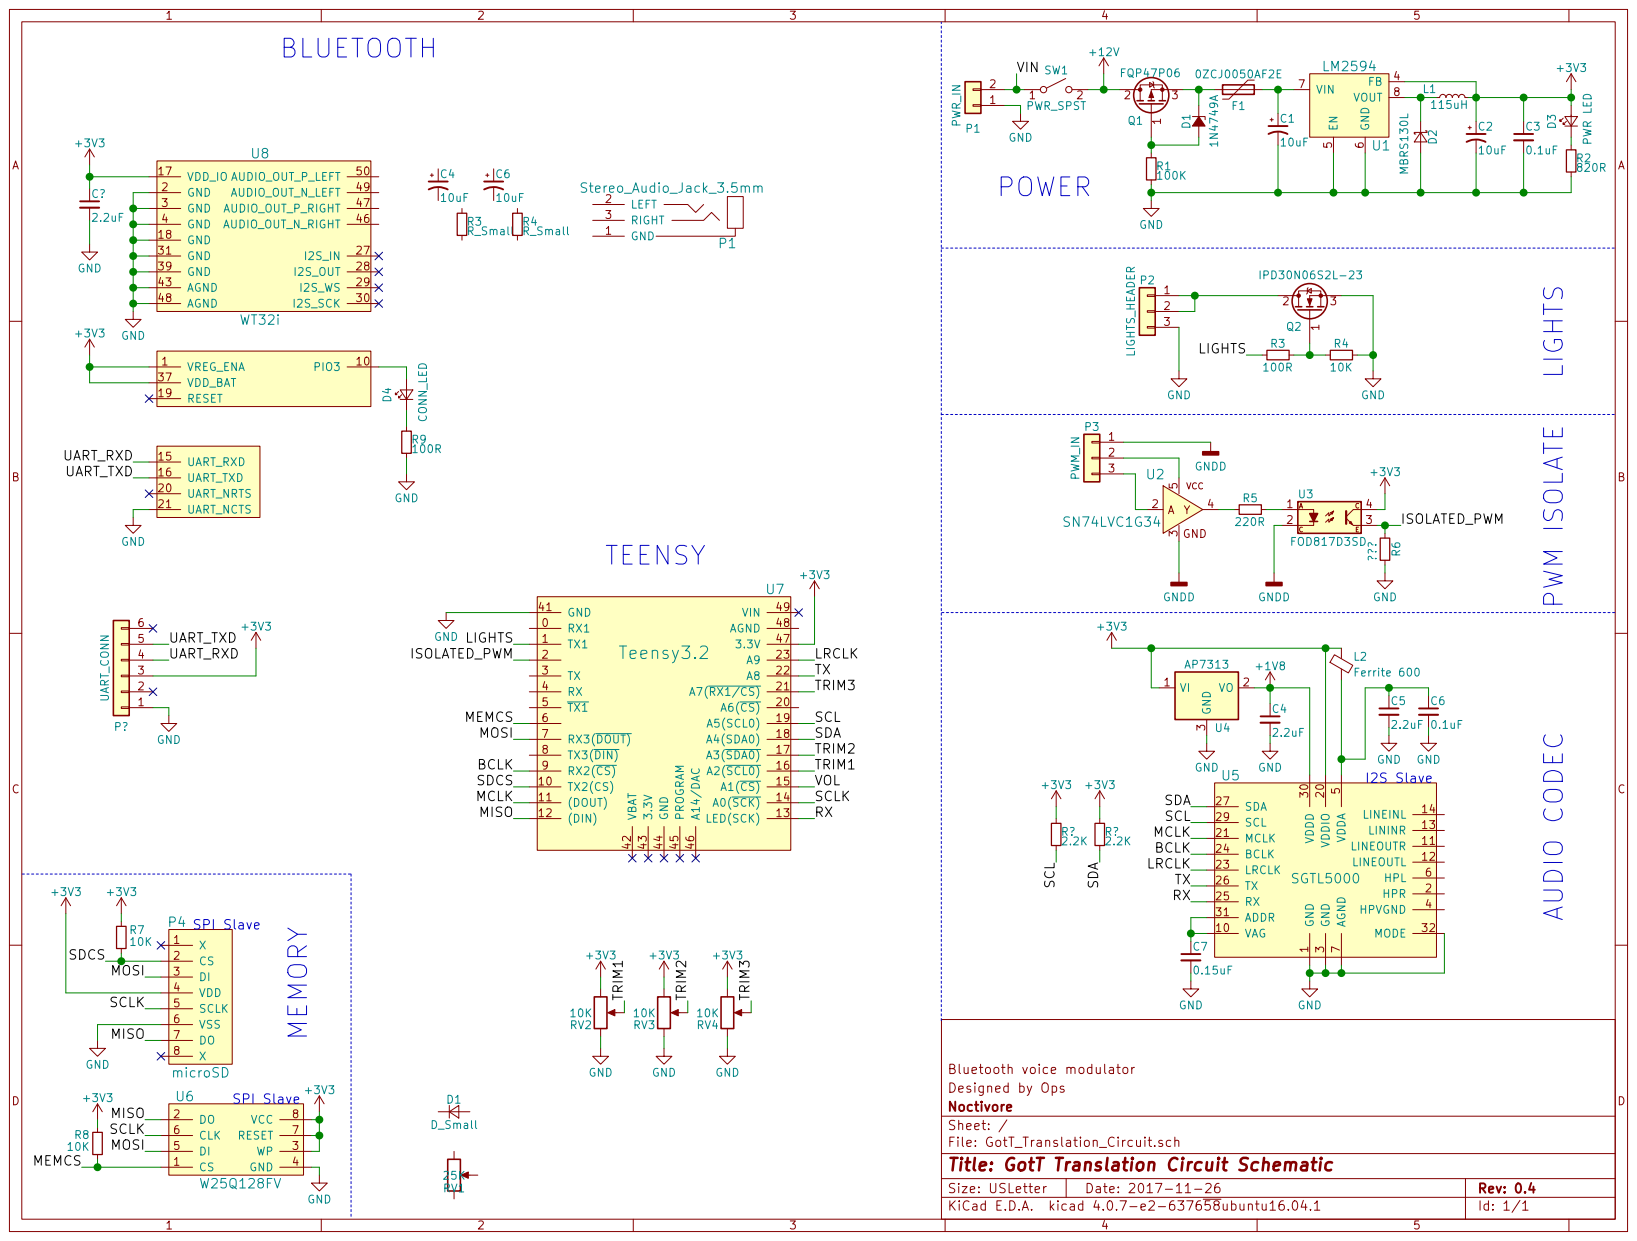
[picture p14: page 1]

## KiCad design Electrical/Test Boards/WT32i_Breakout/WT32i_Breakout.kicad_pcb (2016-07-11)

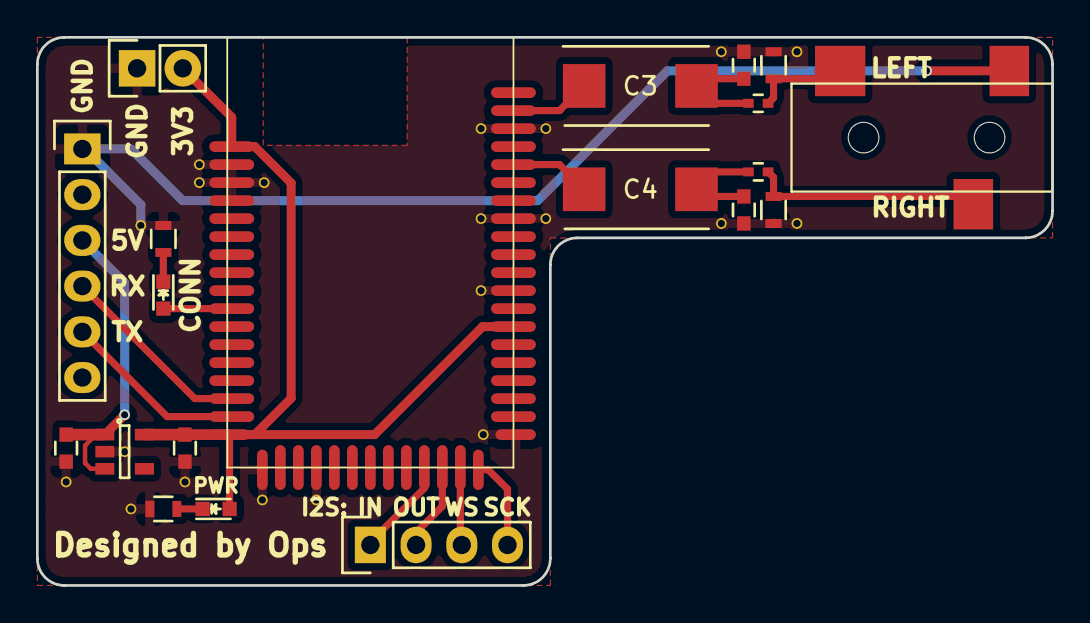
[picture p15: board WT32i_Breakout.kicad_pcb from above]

Board: 2 copper layers, 56.4 x 30.5 mm, 20 parts (0 on the bottom side), 18 nets.

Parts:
C1, C2: 2.2uF; C_0603
C3, C4: 330uF/6.3V; TantalC_SizeD_EIA-7343_Reflow
C5, C6: 33pF; C_0603
D2: CONN_LED; LED_0603
D3: PWR_LED; LED_0603
L1, L2: 33nH; C_0402
P1: UART_CONN; Socket_Strip_Straight_1x06
P2: I2S_CONN; Socket_Strip_Straight_1x04
P3: PWR_CONN; Socket_Strip_Straight_1x02
P4: Stereo_Audio_Jack_3.5mm; CUI_Stereo_Audio_Jack
R1: 100; R_0603
R2: 820; R_0603
R3, R4: 1M; R_0603
U1: WT32i
U2: TPS79933; SOT-23-5

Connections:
+3V3: C2.1, D3.2, P3.2, U1.1, U1.17, U1.37, U2.5
+5V: C1.1, P1.3, U2.1, U2.3
/I2S_IN: P2.1, U1.27
/I2S_OUT: P2.2, U1.28
/I2S_SCK: P2.4, U1.30
/I2S_WS: P2.3, U1.29
/UART_RXD: P1.4, U1.15
/UART_TXD: P1.5, U1.16
GND: C1.2, C2.2, C5.2, C6.1, P1.1, P3.1, R1.2, R2.2, R3.1, R4.2, U1.2, U1.3, U1.4, U1.18, U1.21, U1.31, U1.39, U1.43, U1.48, U2.2
unnamed: C3.1, U1.49
unnamed: C3.2, C6.2, L1.1
unnamed: C4.1, U1.46
unnamed: C4.2, C5.1, L2.2
unnamed: D2.1, R1.1
unnamed: D2.2, U1.10
unnamed: D3.1, R2.1
unnamed: L1.2, P4.2, R3.2
unnamed: L2.1, P4.3, R4.1

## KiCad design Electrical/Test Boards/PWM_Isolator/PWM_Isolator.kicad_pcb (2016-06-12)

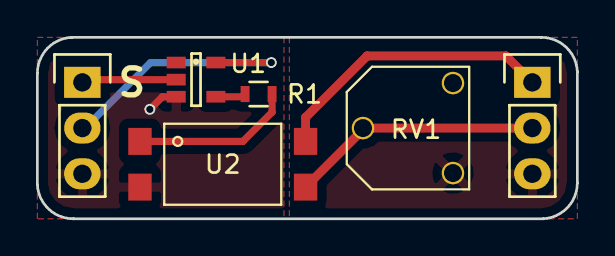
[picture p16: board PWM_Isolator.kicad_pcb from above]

Board: 2 copper layers, 30.0 x 10.1 mm, 6 parts (0 on the bottom side), 8 nets.

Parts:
P1: RC_HEADER; Pin_Header_Straight_1x03
P2: OUT_HEADER; Pin_Header_Straight_1x03
R1: 220; R_0603
RV1: 10K; 3306F-1-103_Trim_Pot
U1: SN74LVC1G34; SOT-23-5
U2: FOD817D3SD; FOD817D3SD_Optocoupler

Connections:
+3V3: P2.1, U2.4
+5V: P1.2, U1.5
GND: P2.3, RV1.1
GNDD: P1.3, U1.3, U2.2
unnamed: P1.1, U1.2
unnamed: P2.2, RV1.2, U2.3
unnamed: R1.1, U2.1
unnamed: R1.2, U1.4

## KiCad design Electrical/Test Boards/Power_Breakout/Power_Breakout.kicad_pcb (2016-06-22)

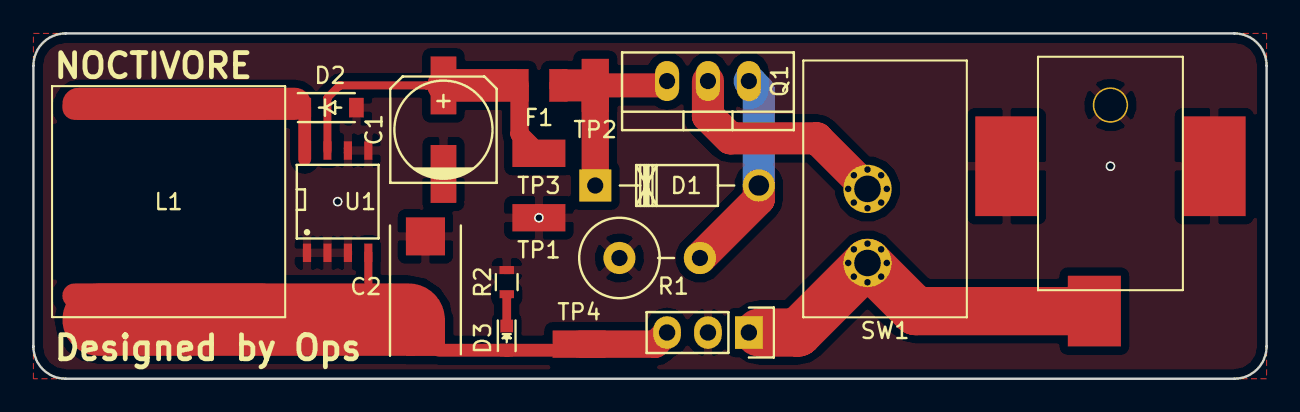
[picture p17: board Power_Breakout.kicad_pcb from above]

Board: 2 copper layers, 76.6 x 21.5 mm, 18 parts (0 on the bottom side), 9 nets.

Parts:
C1: 68uF; c_elec_6.3x7.7
C2: 10uF; TantalC_SizeD_EIA-7343_Reflow
CON1: BARREL_JACK; PJ-036AH-SMT-TR_Barrel_Jack
D1: 1N4749A; Diode_DO-41_SOD81_Horizontal_RM10
D2: MBRS130L; SOD-123
D3: PWR LED; LED_0603
F1: 0ZCJ0050AF2E; Fuse_SMD1206_Reflow
L1: 100uH; PE-53820SNL_Pulse_Inductor
P1: Header; Pin_Header_Straight_1x03
Q1: FQP47P06; TO-220_Neutral123_Vertical
R1: 100K; Resistor_Vertical_RM5mm
R2: 100; R_0603
SW1: GF-123-0054
TP1, TP2, TP3, TP4: TP1; RCS-0C_Test_Point
U1: LM2594; SOIC-8-N

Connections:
+3V3: C2.1, D3.2, L1.2, P1.3, TP4.1, U1.4
/VIN: CON1.1, P1.1, SW1.1
GND: C1.2, C2.2, CON1.2, CON1.3, D2.2, P1.2, R1.1, R2.2, TP1.1, U1.1, U1.2, U1.3, U1.5, U1.6
unnamed: C1.1, F1.2, TP3.1, U1.7
unnamed: D1.1, F1.1, Q1.3, TP2.1
unnamed: D1.2, Q1.1, R1.2
unnamed: D2.1, L1.1, U1.8
unnamed: D3.1, R2.1
unnamed: Q1.2, SW1.2

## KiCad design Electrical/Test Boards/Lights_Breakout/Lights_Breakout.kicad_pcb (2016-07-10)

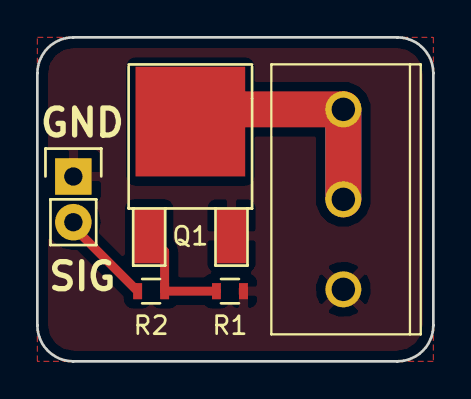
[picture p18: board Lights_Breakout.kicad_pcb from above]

Board: 2 copper layers, 22.0 x 18.0 mm, 5 parts (0 on the bottom side), 4 nets.

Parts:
P1: LIGHTS_HEADER; 1935174_Phoenix_Contact_01X03
P2: SIGNAL_HEADER; Socket_Strip_Straight_1x02
Q1: IPD30N06S2L-23; TO-252-2Lead
R1: 10K; R_0603
R2: 100; R_0603

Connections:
GND: P1.1, P2.1, Q1.3, R1.1
unnamed: P1.2, P1.3, Q1.2
unnamed: P2.2, R2.2
unnamed: Q1.1, R1.2, R2.1

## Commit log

2016-05-26 Create KiCad project
    [GotT_Translation_Circuit.kicad_pcb, GotT_Translation_Circuit.sch]
2016-05-27 add parts, footprints, docs, schems
    [BOM.xlsx, GotT_Translation_Circuit.sch]
2016-05-31 BOM update
    [BOM.xlsx]
2016-05-31 schematic update
    [GotT_Translation_Circuit.kicad_pcb, GotT_Translation_Circuit.sch]
2016-06-02 Add WT32i test board
    [BOM.xlsx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]
2016-06-03 Test board updates
    [BOM.xlsx, GotT_Translation_Circuit.sch, Power_Breakout.kicad_pcb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]
2016-06-04 Add PWM Isolator test board
    [BOM.xlsx, PWM_Isolator.kicad_pcb, PWM_Isolator.sch]
2016-06-08 Power test board updates
    [BOM.xlsx, Power_Breakout.sch]
2016-06-11 PWM isolator updates
    [PWM_Isolator.kicad_pcb, PWM_Isolator.sch]
2016-06-11 Add lights breakout board
    [BOM.xlsx, Lights_Breakout.kicad_pcb, Lights_Breakout.sch]
2016-06-12 Gerber generation
    [Lights_Breakout.kicad_pcb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]
2016-06-12 Add test board README
2016-06-12 Add test board schems/layouts
    [WT32i_Breakout.sch]
2016-06-13 WT32i test board updates
    [BOM.xlsx, WT32i_Breakout.sch]
2016-06-20 png optimization, move BOM
    [BOM.xlsx]
2016-06-22 gerber/README updates
    [Lights_Breakout.kicad_pcb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]
2016-06-23 Gerber/BOM updates
    [BOM.xlsx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]
2016-07-09 Power test board corrections
    [BOM.xlsx, Power_Breakout.sch]
2016-07-10 Lights test board corrections
    [Lights_Breakout-B.Cu.gbl, Lights_Breakout-B.Mask.gbs, Lights_Breakout-B.SilkS.gbo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]
2016-09-04 Schematic, documentation update
    [BOM.xlsx, GotT_Translation_Circuit.sch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]
2016-09-04 Combine sub-circuits, update BOM/lib, add PDFs
    [BOM.xlsx, GotT_Translation_Circuit.sch]
2017-11-26 schematic updates
    [GotT_Translation_Circuit.sch]
